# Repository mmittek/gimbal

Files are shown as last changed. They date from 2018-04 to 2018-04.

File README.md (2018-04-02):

# 3-AXIS GIMBAL PROJECT
Poorly documented attempt to build an inexpensive 3-axis gimbal using STM32FX uC and MPU6050/9250 IMU. Main goal is to learn how to use STM32CubeMX and maintain such project (it's my first real-world use of STM32FX-series uC).

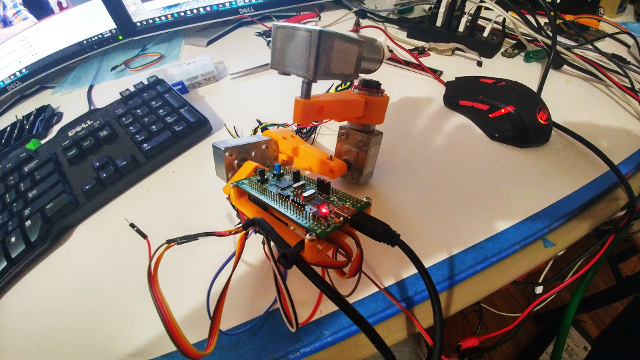
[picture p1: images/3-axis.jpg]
Single axis assembly


1-axis demo: https://www.youtube.com/watch?v=dBaz5YtMMdg     
2-axis demo: https://www.youtube.com/watch?v=Pzl1FiPx8YI

## Features
- STM32F100 running at 24Mhz
- Eclipse Makefile project
- Pins defined and configuration managed using STM32CubeMX (http://www.st.com/en/development-tools/stm32cubemx.html)
- IMU sampled at 100Hz using Invense's API
- Complementary filter for 3-axis (relative) orientation estimation
- PID loops for motor speed control with PWM-controlled enable pins

## Components
- STM32F100 discovery board (http://www.st.com/en/evaluation-tools/stm32vldiscovery.html)
- GY-521 MPU6050 module board (https://playground.arduino.cc/Main/MPU-6050)
- JLink JTAG EDU (https://www.digikey.com/products/en?mpart=8.08.90%20J-LINK%20EDU&v=899)
- Inexpensive JGY-371 motors readily available on eBay (https://media.digikey.com/pdf/Data%20Sheets/Seeed%20Technology/108990007_Web.pdf)
- Some 3D-printed parts for the assembly
- L298N motor control boards readily available online (https://www.amazon.com/DROK-Controller-H-Bridge-Mega2560-Duemilanove/dp/B00CAG6GX2)

## References
- L298N Solid Works model taken from https://grabcad.com/library/driver-l298n-1
- GY6050/GY9250 Solid Works model taken from https://grabcad.com/library/mpu-92-65-1
- Connecting J-Link to STM32-Discovery eval boards application note: https://www.segger.com/downloads/application-notes/AN00021

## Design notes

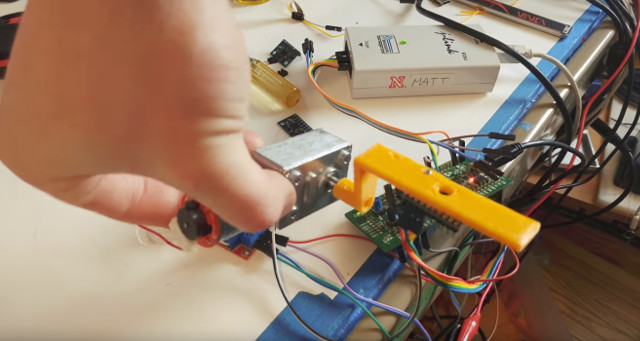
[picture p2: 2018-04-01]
images/1-axis.jpg

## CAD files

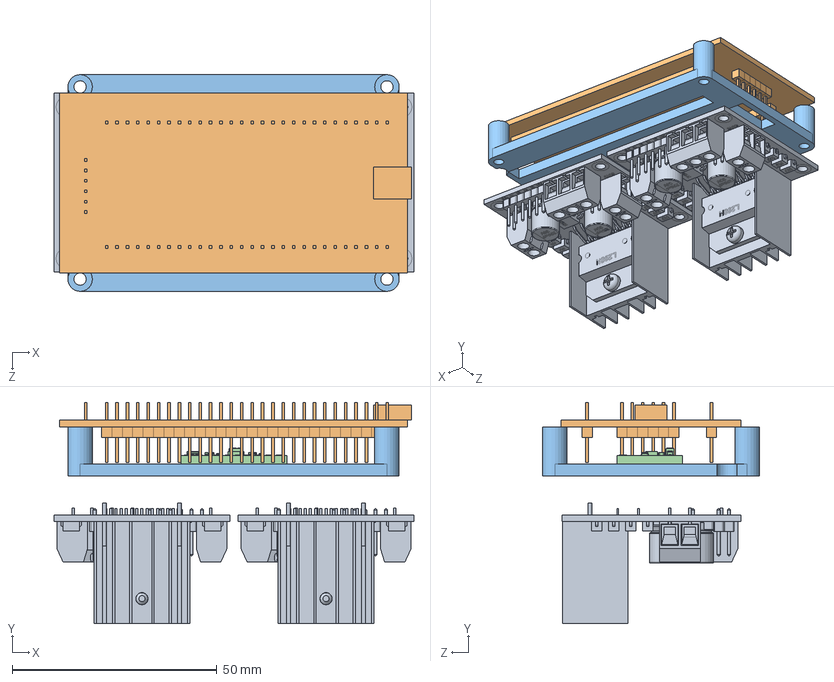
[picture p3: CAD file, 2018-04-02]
models/project-box-assembly.SLDASM
88.0 x 54.1 x 53.0 mm
L298N x 2
STM32F100-discovery-board-simplified
Part2^project-box-assembly
gy6050

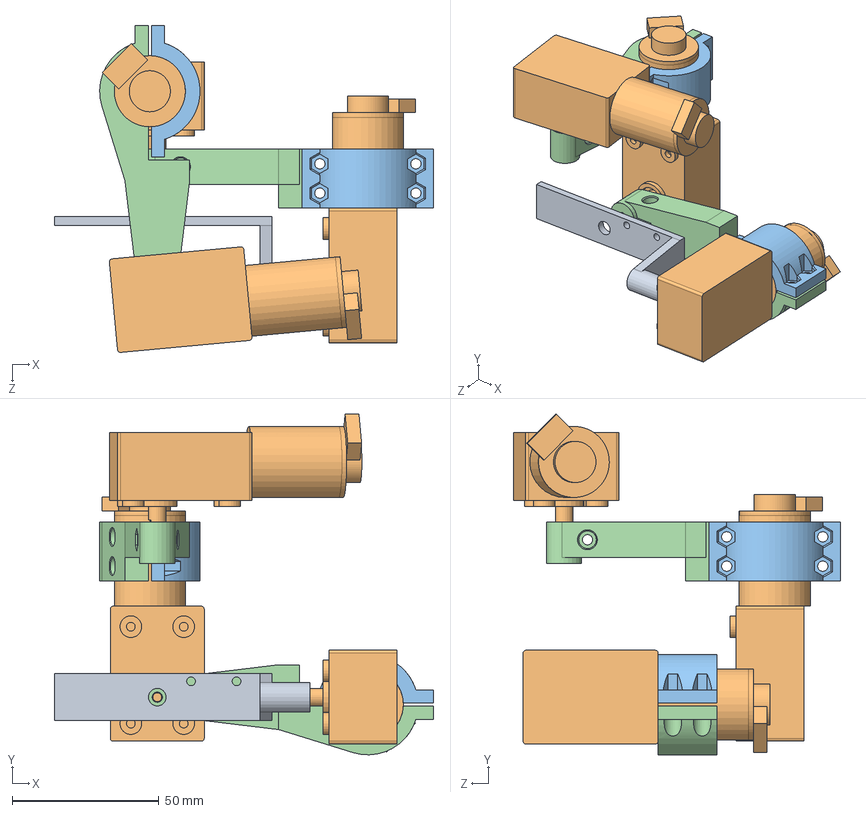
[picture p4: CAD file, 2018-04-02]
models/assembly-3-axis.SLDASM
129.1 x 116.0 x 111.3 mm
CameraArm
MotorWithGearbox x 3
TopClamp^assembly-3-axis x 2
BottomClamp^assembly-3-axis x 2

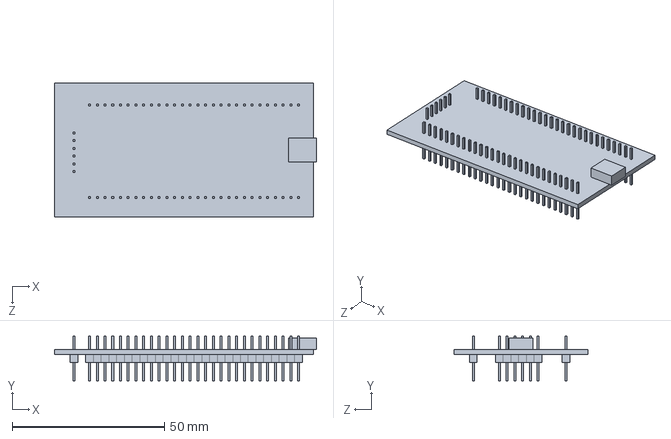
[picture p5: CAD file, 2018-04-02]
models/STM32F100-discovery-board-simplified.SLDPRT
86.0 x 14.7 x 44.0 mm

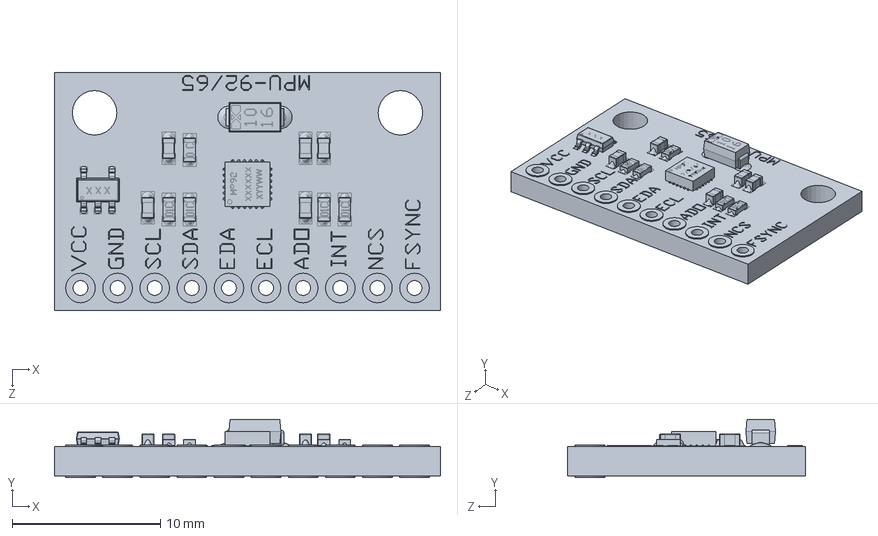
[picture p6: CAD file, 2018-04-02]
models/gy6050.SLDPRT
26.0 x 3.91 x 16.0 mm

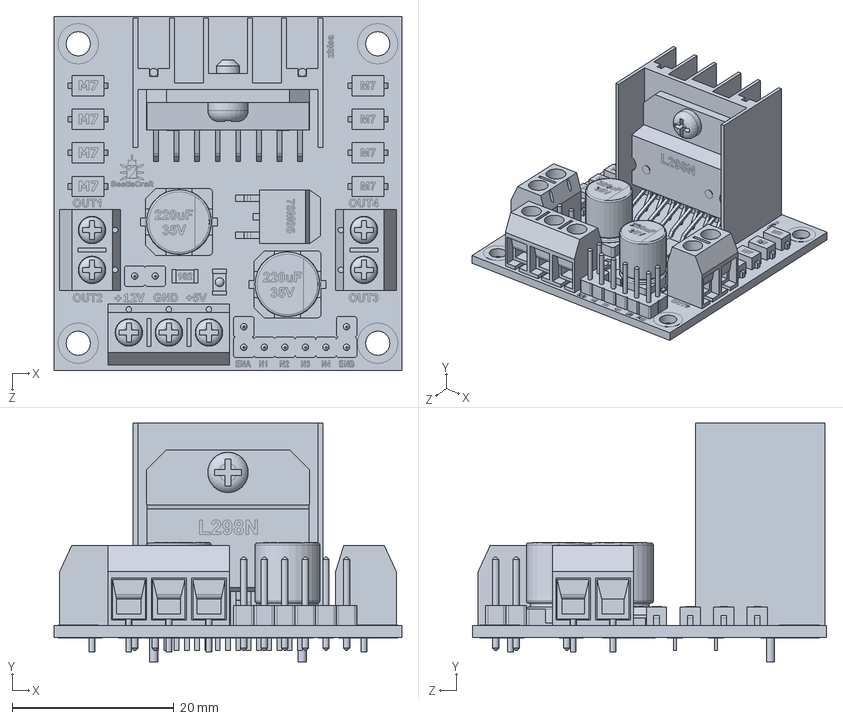
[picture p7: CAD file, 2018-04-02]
models/L298N.SLDPRT
43.0 x 29.5 x 43.8 mm

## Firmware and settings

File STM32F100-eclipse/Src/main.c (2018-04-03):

/**
  ******************************************************************************
  * @file           : main.c
  * @brief          : Main program body
  ******************************************************************************
  ** This notice applies to any and all portions of this file
  * that are not between comment pairs USER CODE BEGIN and
  * USER CODE END. Other portions of this file, whether 
  * inserted by the user or by software development tools
  * are owned by their respective copyright owners.
  *
  * COPYRIGHT(c) 2018 STMicroelectronics
  *
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
  ******************************************************************************
  */
/* Includes ------------------------------------------------------------------*/
#include "main.h"
#include "stm32f1xx_hal.h"

/* USER CODE BEGIN Includes */
#include "mpu.h"
#include "inv_mpu.h"
#include "mpu9250.h"
#include "i2c.h"
#include "motor.h"
#include "PID.h"
/* USER CODE END Includes */

I2C_HandleTypeDef hi2c1;

TIM_HandleTypeDef htim15;
TIM_HandleTypeDef htim16;
TIM_HandleTypeDef htim17;

USART_HandleTypeDef husart1;

/* USER CODE BEGIN PV */

/* USER CODE END PV */

void SystemClock_Config(void);
static void MX_GPIO_Init(void);
static void MX_I2C1_Init(void);
static void MX_USART1_Init(void);
static void MX_TIM16_Init(void);
static void MX_TIM17_Init(void);
static void MX_TIM15_Init(void);
                                    
void HAL_TIM_MspPostInit(TIM_HandleTypeDef *htim);
                                
                                
                                

/* USER CODE BEGIN PFP */

/* USER CODE END PFP */

/* USER CODE BEGIN 0 */
mpu9250_t 	m_mpu9250;
PID_t		m_roll_PID;
motor_t 	m_roll_motor;

PID_t		m_pitch_PID;
motor_t 	m_pitch_motor;

void mpu9250_empl_data_handler(mpu9250_t* p_mpu9250, mpu9250_empl_data_type_t type, long *data, unsigned long timestamp) {

}

volatile float roll_speed = 0.0f;
volatile float pitch_speed = 0.0f;

void mpu9250_euler_handler(mpu9250_t* p_mpu9250, float pitch, float roll, float yaw) {
	roll_speed = PID_feed(&m_roll_PID, roll);
	pitch_speed = PID_feed(&m_pitch_PID, pitch);

	motor_go(&m_roll_motor, (int)roll_speed, fabs(roll_speed)/180.0f);
	motor_go(&m_pitch_motor, (int)pitch_speed, fabs(pitch_speed)/180.0f);
}

void mpu9250_fault_handler(mpu9250_t* p_mpu9250, mpu9250_fault_type_t fault) {
	motor_stop(&m_roll_motor);
	motor_stop(&m_pitch_motor);
	char buf[64];
	sprintf(buf, "IMU ERROR: %d\r\n", fault);
	HAL_USART_Transmit(&husart1, buf, strlen(buf), 1000);

}

/* USER CODE END 0 */

/**
  * @brief  The application entry point.
  *
  * @retval None
  */
int main(void)
{
  /* MCU Configuration----------------------------------------------------------*/

  /* Reset of all peripherals, Initializes the Flash interface and the Systick. */


	HAL_Init();

  /* Configure the system clock */
  SystemClock_Config();

  /* Initialize all configured peripherals */
  MX_GPIO_Init();
  MX_I2C1_Init();
  MX_USART1_Init();
  MX_TIM16_Init();
  MX_TIM17_Init();
  MX_TIM15_Init();
  /* USER CODE BEGIN 2 */
  i2c_set_instance(&hi2c1);

  PID_init(&m_roll_PID, 12.0f, 0.0001, 1.0f);
  PID_init(&m_pitch_PID, 16.0f, 0.0001, 4.0f);
//    PID_init(&m_roll_PID, 16.0f, 0.0001, 4.0f);
//    PID_init(&m_pitch_PID, 32.0f, 0.0001, 16.0f);

  PID_setpoint(&m_roll_PID, 0, 2);
  PID_setpoint(&m_pitch_PID, 0, 2);

  motor_init(&m_roll_motor, GPIOC, GPIO_PIN_9, GPIOC, GPIO_PIN_7, &htim16, TIM_CHANNEL_1);
  motor_init(&m_pitch_motor, GPIOC, GPIO_PIN_8, GPIOC, GPIO_PIN_6, &htim17, TIM_CHANNEL_1);
  char buf[64];


  HAL_Delay(100);

  mpu9250_conf_t mpu9250_conf;
  mpu9250_conf.empl_data_handler 	=mpu9250_empl_data_handler;
  mpu9250_conf.euler_handler 		= mpu9250_euler_handler;
  mpu9250_conf.fault_handler 		= mpu9250_fault_handler;

  // Gyro bias obtained empirically on Apr 2 2018
  mpu9250_conf.gyro_bias[0] 		= 0;
  mpu9250_conf.gyro_bias[1] 		= 0;
  mpu9250_conf.gyro_bias[2] 		= 0;
  mpu9250_init(&m_mpu9250, &mpu9250_conf);

  /* USER CODE END 2 */

  /* Infinite loop */
  /* USER CODE BEGIN WHILE */
  while (1)
  {
  /* USER CODE END WHILE */

  /* USER CODE BEGIN 3 */
	  mpu9250_mpu_sampling(&m_mpu9250);

		if(m_mpu9250.num_samples % (2*DEFAULT_MPU_HZ) == 0) {

			memset(buf, 0, sizeof(buf));
			sprintf(buf, "%d,%d,%d,%d,%d\r\n", (int)m_mpu9250.roll, (int)m_mpu9250.pitch, (int)m_mpu9250.yaw,(int)roll_speed,(int)m_roll_PID.e_prev);
			HAL_USART_Transmit(&husart1, buf, strlen(buf), 1000);

		}




  }
  /* USER CODE END 3 */

}

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


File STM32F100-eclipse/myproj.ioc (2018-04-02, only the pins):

Mcu.UserName=STM32F100RBTx
PA10.Signal=USART1_RX
PA13.Signal=SYS_JTMS-SWDIO
PA14.Signal=SYS_JTCK-SWCLK
PA15.Signal=SYS_JTDI
PA2.Signal=S_TIM15_CH1
PA6.Signal=S_TIM16_CH1
PA7.Signal=S_TIM17_CH1
PA8.Signal=USART1_CK
PA9.Signal=USART1_TX
PB3.Signal=SYS_JTDO-TRACESWO
PB8.Signal=I2C1_SCL
PB9.Signal=I2C1_SDA
PC6.Signal=GPIO_Output
PC7.Signal=GPIO_Output
PC8.Signal=GPIO_Output
PC9.Signal=GPIO_Output

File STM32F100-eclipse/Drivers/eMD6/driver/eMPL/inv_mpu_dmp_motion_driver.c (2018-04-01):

/*
 $License:
    Copyright (C) 2011-2012 InvenSense Corporation, All Rights Reserved.
    See included License.txt for License information.
 $
 */
/**
 *  @addtogroup  DRIVERS Sensor Driver Layer
 *  @brief       Hardware drivers to communicate with sensors via I2C.
 *
 *  @{
 *      @file       inv_mpu_dmp_motion_driver.c
 *      @brief      DMP image and interface functions.
 *      @details    All functions are preceded by the dmp_ prefix to
 *                  differentiate among MPL and general driver function calls.
 */
#include <stdio.h>
#include <stdint.h>
#include <stdlib.h>
#include <string.h>
#include <math.h>
#include "inv_mpu.h"
#include "inv_mpu_dmp_motion_driver.h"
#include "dmpKey.h"
#include "dmpmap.h"

/* The following functions must be defined for this platform:
 * i2c_write(unsigned char slave_addr, unsigned char reg_addr,
 *      unsigned char length, unsigned char const *data)
 * i2c_read(unsigned char slave_addr, unsigned char reg_addr,
 *      unsigned char length, unsigned char *data)
 * delay_ms(unsigned long num_ms)
 * get_ms(unsigned long *count)
 */
#if defined EMPL_TARGET_STM32F100
#include "utils.h"
#include "stm32f1xx_hal.h"
#include "i2c.h"
#define get_ms      utils_get_ms
#define delay_ms	HAL_Delay
#define log_i(...)     do {} while (0)
#define log_e(...)     do {} while (0)
#define __no_operation() {}
#elif defined MOTION_DRIVER_TARGET_MSP430
#include "msp430.h"
#include "msp430_clock.h"
#define delay_ms    msp430_delay_ms
#define get_ms      msp430_get_clock_ms
#define log_i(...)     do {} while (0)
#define log_e(...)     do {} while (0)

#elif defined EMPL_TARGET_MSP430
#include "msp430.h"
#include "msp430_clock.h"
#include "log.h"
#define delay_ms    msp430_delay_ms
#define get_ms      msp430_get_clock_ms
#define log_i       MPL_LOGI
#define log_e       MPL_LOGE

#elif defined EMPL_TARGET_UC3L0
/* Instead of using the standard TWI driver from the ASF library, we're using
 * a TWI driver that follows the slave address + register address convention.
 */
#include "delay.h"
#include "sysclk.h"
#include "log.h"
#include "uc3l0_clock.h"
/* delay_ms is a function already defined in ASF. */
#define get_ms  uc3l0_get_clock_ms
#define log_i       MPL_LOGI
#define log_e       MPL_LOGE

#else
#error  Gyro driver is missing the system layer implementations.
#endif

/* These defines are copied from dmpDefaultMPU6050.c in the general MPL
 * releases. These defines may change for each DMP image, so be sure to modify
 * these values when switching to a new image.
 */
#define CFG_LP_QUAT             (2712)
#define END_ORIENT_TEMP         (1866)
#define CFG_27                  (2742)
#define CFG_20                  (2224)
#define CFG_23                  (2745)
#define CFG_FIFO_ON_EVENT       (2690)
#define END_PREDICTION_UPDATE   (1761)
#define CGNOTICE_INTR           (2620)
#define X_GRT_Y_TMP             (1358)
#define CFG_DR_INT              (1029)
#define CFG_AUTH                (1035)
#define UPDATE_PROP_ROT         (1835)
#define END_COMPARE_Y_X_TMP2    (1455)
#define SKIP_X_GRT_Y_TMP        (1359)
#define SKIP_END_COMPARE        (1435)
#define FCFG_3                  (1088)
#define FCFG_2                  (1066)
#define FCFG_1                  (1062)
#define END_COMPARE_Y_X_TMP3    (1434)
#define FCFG_7                  (1073)
#define FCFG_6                  (1106)
#define FLAT_STATE_END          (1713)
#define SWING_END_4             (1616)
#define SWING_END_2             (1565)
#define SWING_END_3             (1587)
#define SWING_END_1             (1550)
#define CFG_8                   (2718)
#define CFG_15                  (2727)
#define CFG_16                  (2746)
#define CFG_EXT_GYRO_BIAS       (1189)
#define END_COMPARE_Y_X_TMP     (1407)
#define DO_NOT_UPDATE_PROP_ROT  (1839)
#define CFG_7                   (1205)
#define FLAT_STATE_END_TEMP     (1683)
#define END_COMPARE_Y_X         (1484)
#define SKIP_SWING_END_1        (1551)
#define SKIP_SWING_END_3        (1588)
#define SKIP_SWING_END_2        (1566)
#define TILTG75_START           (1672)
#define CFG_6                   (2753)
#define TILTL75_END             (1669)
#define END_ORIENT              (1884)
#define CFG_FLICK_IN            (2573)
#define TILTL75_START           (1643)
#define CFG_MOTION_BIAS         (1208)
#define X_GRT_Y                 (1408)
#define TEMPLABEL               (2324)
#define CFG_ANDROID_ORIENT_INT  (1853)
#define CFG_GYRO_RAW_DATA       (2722)
#define X_GRT_Y_TMP2            (1379)

#define D_0_22                  (22+512)
#define D_0_24                  (24+512)

#define D_0_36                  (36)
#define D_0_52                  (52)
#define D_0_96                  (96)
#define D_0_104                 (104)
#define D_0_108                 (108)
#define D_0_163                 (163)
#define D_0_188                 (188)
#define D_0_192                 (192)
#define D_0_224                 (224)
#define D_0_228                 (228)
#define D_0_232                 (232)
#define D_0_236                 (236)

#define D_1_2                   (256 + 2)
#define D_1_4                   (256 + 4)
#define D_1_8                   (256 + 8)
#define D_1_10                  (256 + 10)
#define D_1_24                  (256 + 24)
#define D_1_28                  (256 + 28)
#define D_1_36                  (256 + 36)
#define D_1_40                  (256 + 40)
#define D_1_44                  (256 + 44)
#define D_1_72                  (256 + 72)
#define D_1_74                  (256 + 74)
#define D_1_79                  (256 + 79)
#define D_1_88                  (256 + 88)
#define D_1_90                  (256 + 90)
#define D_1_92                  (256 + 92)
#define D_1_96                  (256 + 96)
#define D_1_98                  (256 + 98)
#define D_1_106                 (256 + 106)
#define D_1_108                 (256 + 108)
#define D_1_112                 (256 + 112)
#define D_1_128                 (256 + 144)
#define D_1_152                 (256 + 12)
#define D_1_160                 (256 + 160)
#define D_1_176                 (256 + 176)
#define D_1_178                 (256 + 178)
#define D_1_218                 (256 + 218)
#define D_1_232                 (256 + 232)
#define D_1_236                 (256 + 236)
#define D_1_240                 (256 + 240)
#define D_1_244                 (256 + 244)
#define D_1_250                 (256 + 250)
#define D_1_252                 (256 + 252)
#define D_2_12                  (512 + 12)
#define D_2_96                  (512 + 96)
#define D_2_108                 (512 + 108)
#define D_2_208                 (512 + 208)
#define D_2_224                 (512 + 224)
#define D_2_236                 (512 + 236)
#define D_2_244                 (512 + 244)
#define D_2_248                 (512 + 248)
#define D_2_252                 (512 + 252)
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

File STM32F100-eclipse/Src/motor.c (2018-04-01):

#include "motor.h"
#include <math.h>

void motor_set_pins(motor_t *p_motor, uint8_t A, uint8_t B) {
	HAL_GPIO_WritePin(p_motor->A_port, p_motor->A_pin, A);
	HAL_GPIO_WritePin(p_motor->B_port, p_motor->B_pin, B);
}

void motor_stop(motor_t *p_motor) {
	HAL_TIM_PWM_Stop(p_motor->p_timer_pwm, p_motor->timer_channel);
	motor_set_pins(p_motor, GPIO_PIN_RESET,GPIO_PIN_RESET);
}


HAL_StatusTypeDef motor_set_pwm_config(motor_t *p_motor, float duty_cycle) {
	if(duty_cycle < 0) duty_cycle = 0;
	if(duty_cycle > 1) duty_cycle = 1;

// Take this configuration from main
	TIM_OC_InitTypeDef sConfigOC;
	  sConfigOC.OCMode = TIM_OCMODE_PWM2;
	  sConfigOC.Pulse = (float)p_motor->p_timer_pwm->Init.Period*(1.0-duty_cycle);			// how long is the low
	  sConfigOC.OCPolarity = TIM_OCPOLARITY_HIGH;
	  sConfigOC.OCNPolarity = TIM_OCNPOLARITY_HIGH;
	  sConfigOC.OCFastMode = TIM_OCFAST_DISABLE;
	  sConfigOC.OCIdleState = TIM_OCIDLESTATE_RESET;
	  sConfigOC.OCNIdleState = TIM_OCNIDLESTATE_RESET;
	  return HAL_TIM_PWM_ConfigChannel(p_motor->p_timer_pwm, &sConfigOC, p_motor->timer_channel);
}


float err_sum = 0.0f;
float prev_err = 0.0f;

void motor_go(motor_t *p_motor, int dir, float speed_norm) {
	if(dir == 0 || speed_norm == 0.0f) {
		motor_stop(p_motor);
		return;
	}

	if(dir > 0) {
		motor_set_pins(p_motor, GPIO_PIN_RESET, GPIO_PIN_SET);
	}else if(dir < 0) {
		motor_set_pins(p_motor, GPIO_PIN_SET, GPIO_PIN_RESET);
	}
	motor_set_pwm_config(p_motor, speed_norm);
	HAL_TIM_PWM_Start(p_motor->p_timer_pwm, p_motor->timer_channel);
}


void motor_init(motor_t *p_motor, GPIO_TypeDef *A_port, uint16_t A_pin, GPIO_TypeDef *B_port, uint16_t B_pin, TIM_HandleTypeDef *p_timer_pwm, uint32_t timer_channel) {
	p_motor->A_port = A_port;
	p_motor->B_port = B_port;
	p_motor->A_pin = A_pin;
	p_motor->B_pin = B_pin;
	p_motor->p_timer_pwm = p_timer_pwm;
	p_motor->timer_channel = timer_channel;

}

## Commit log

2018-04-01 Initial commit with codebase and solid works assembly
    [assembly-3-axis.SLDASM]
2018-04-01 Added pic of 1-axis assembly for the readme
2018-04-02 Added 3d model for L298N and a reference in the readme
    [L298N.SLDPRT]
2018-04-02 Added GY6050 3d model and reference in the readme
    [gy6050.SLDPRT]
2018-04-02 Added a simplified STM32F100 board model and some idea for project "box" to live on the gimbal
    [STM32F100-discovery-board-simplified.SLDPRT, assembly-3-axis.SLDASM, project-box-assembly.SLDASM]
2018-04-02 Added 3 axis picture of gimbal assembly
2018-04-02 Added safety feature: motors stop on error with IMU
    [main.c]
2018-04-02 Added 3rd timer
2018-04-02 Added ability to define gyroscope bias

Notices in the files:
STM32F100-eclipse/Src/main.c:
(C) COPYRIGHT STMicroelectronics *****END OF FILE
